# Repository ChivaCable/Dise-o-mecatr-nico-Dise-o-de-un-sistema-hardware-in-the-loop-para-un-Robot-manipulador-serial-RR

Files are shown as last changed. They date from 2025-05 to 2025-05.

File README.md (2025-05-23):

# Sistema-hardware-in-the-loop-para-un-Robot-manipulador-serial-RR

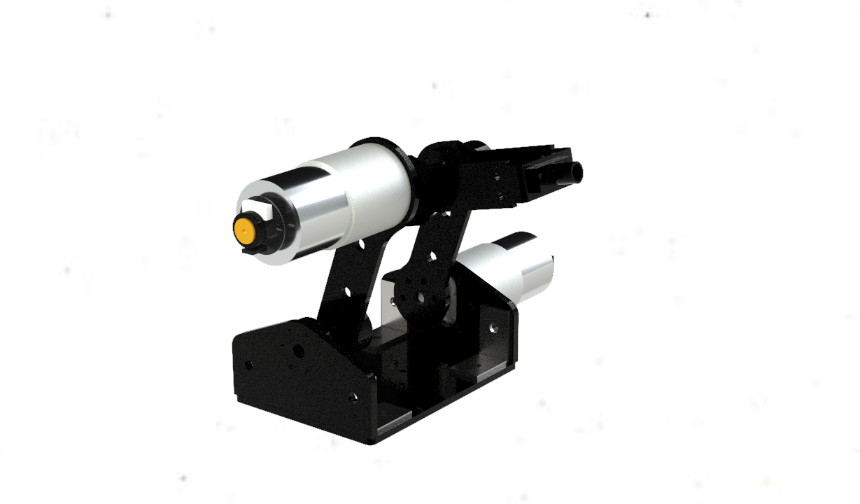
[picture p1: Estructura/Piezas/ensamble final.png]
Image_Alt


# Gz y Rviz

https://github.com/user-attachments/assets/f8c596f3-bc3e-4921-8bc3-12ca6fd54891

# Espacio de trabajo

En este espacio de trabajo usamos ROS 2 y es una estructura de carpetas donde se organizan y construyen los paquetes del sistema robótico. Para trabajar en el espacio de trabajo se debe seguir estos pasos.

# Construir el espacio de trabajo

```bash
cd ros-ws  
colcon build
```

# Configurar el espacio de trabajo
Es necesario cargar ROS2 al sistema y cargar el espacio de trabajo personalizado cada que se realicen cambios.

```bash
source install/setup.bash
source /opt/ros/jazzy/setup.bash
```
# Ejecutar lanzador
El lanzador es el codigo que permite iniciar los multiples nodos que tiene el robot y las configuraciones del mismo de manera simultanea, de manera que con solo un comando se ejecuta el sistema.

```bash
ros2 launch my_robot_planar gazebo_launch.py
```
# Topicos
Gracias a los tópicos en ROS 2, podemos enviar comandos para mover el robot de forma sencilla y eficiente. Esto permite que diferentes nodos se comuniquen y coordinen sus acciones en tiempo real.

# Publicar topicos
En una nueva terminal carga ROS 2 del sistema.
```bash
source /opt/ros/jazzy/setup.bash
```
Lo siguiente es publicar los topicos en la terminal.

Topicos de Gz (usa radianes para mover joint1 y joint2).
```bash
ros2 topic pub /topic_1 std_msgs/msg/Float64 "{data: 1.5}" --once
ros2 topic pub /topic_2 std_msgs/msg/Float64 "{data: 1.5}" --once
```
Topicos del Arduino (usa coordenadas).
```bash
ros2 topic pub /position_command geometry_msgs/msg/Point "{x: -7.97, y: 8.29, z: 0.0}" -1
```
# PCB
Es la base sobre la que se montan y conectan los componentes electrónicos del sistema.

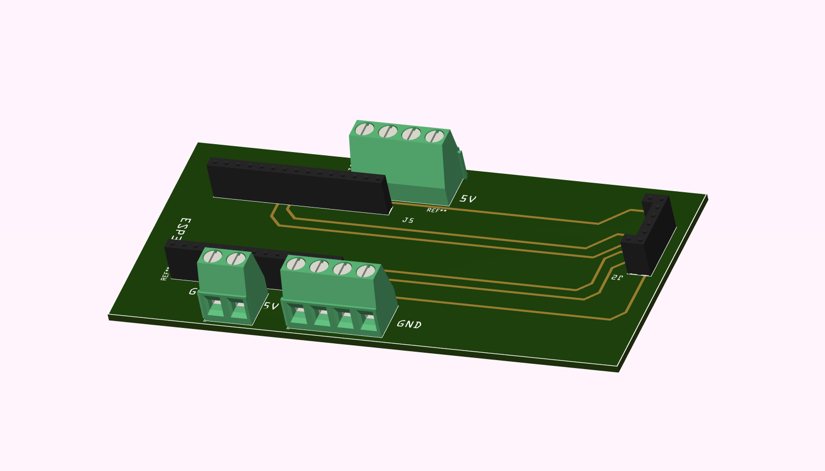
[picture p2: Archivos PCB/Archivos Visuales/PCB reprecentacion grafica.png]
PCB Representación gráfica


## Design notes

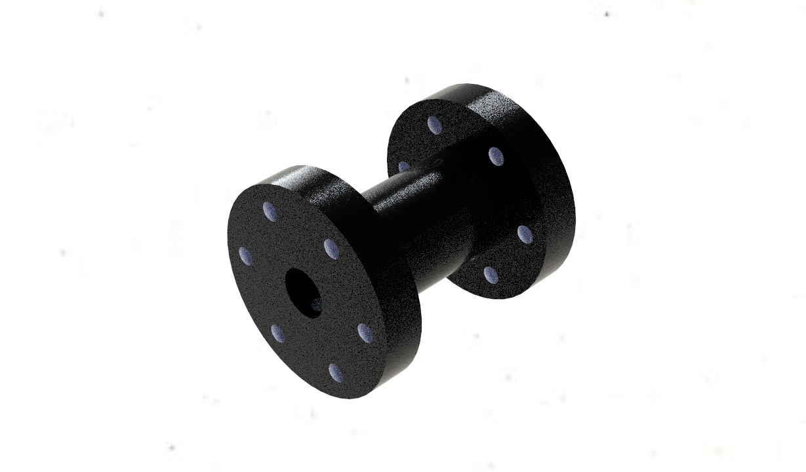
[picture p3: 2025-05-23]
Estructura/Piezas/p3dm double couple_Beauty.jpg

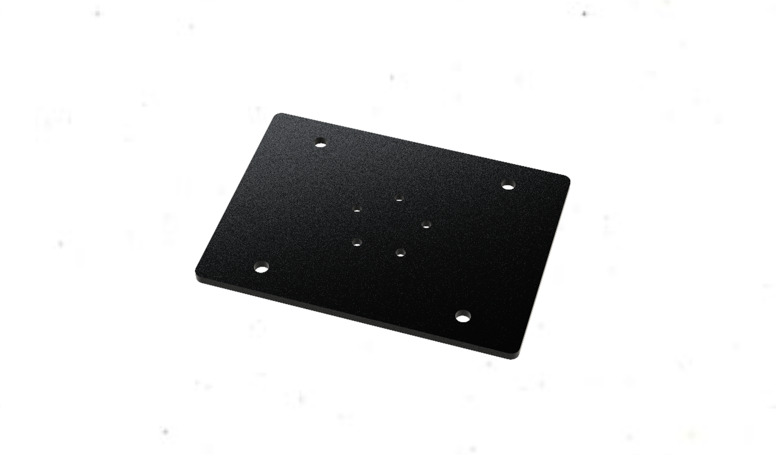
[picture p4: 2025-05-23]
Estructura/Piezas/base.png

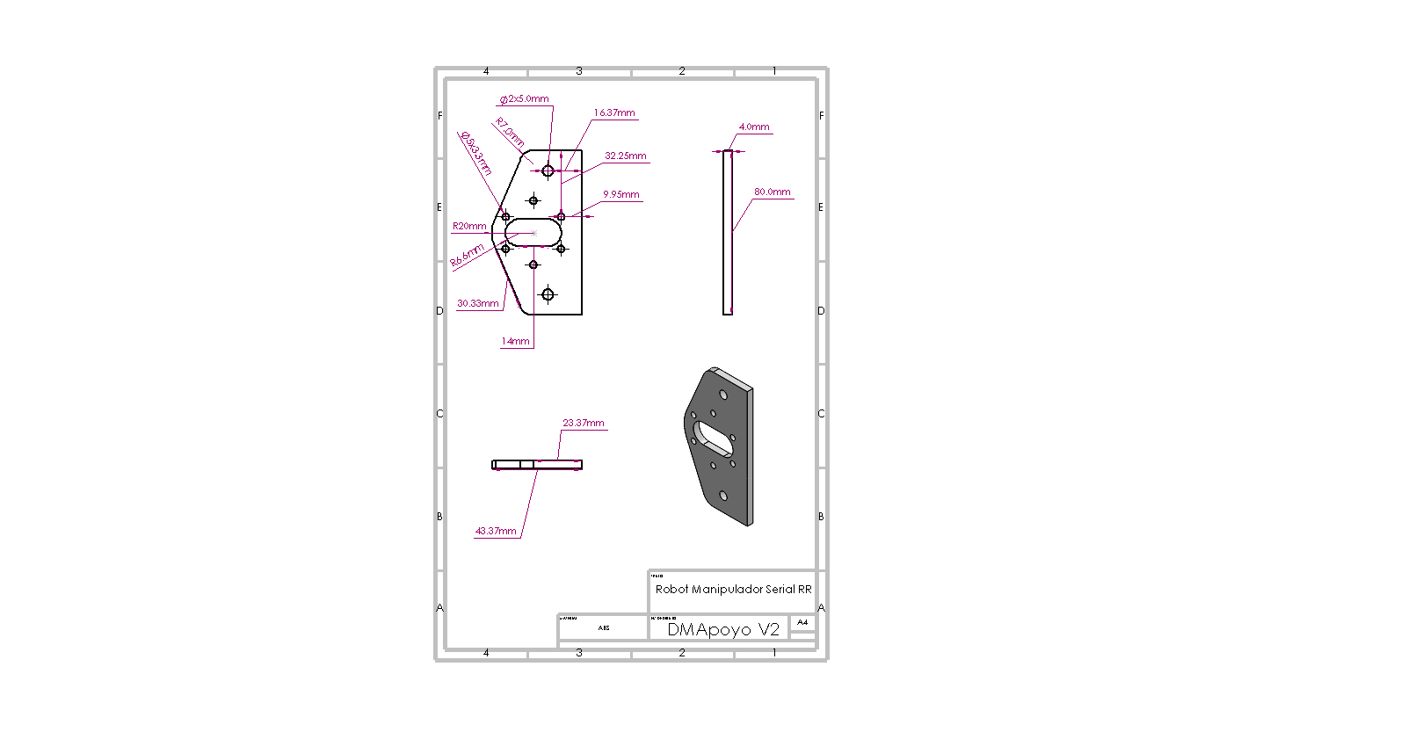
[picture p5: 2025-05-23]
Estructura/Planos/DMApoyo V2.PNG

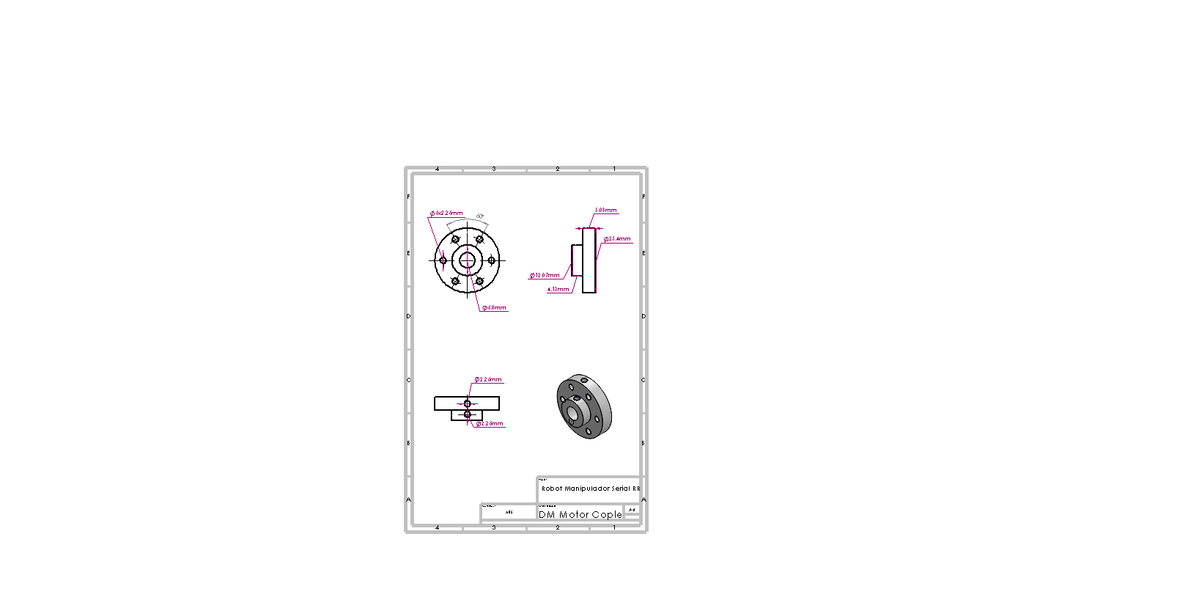
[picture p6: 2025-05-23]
Estructura/Planos/DMMotorCople.PNG

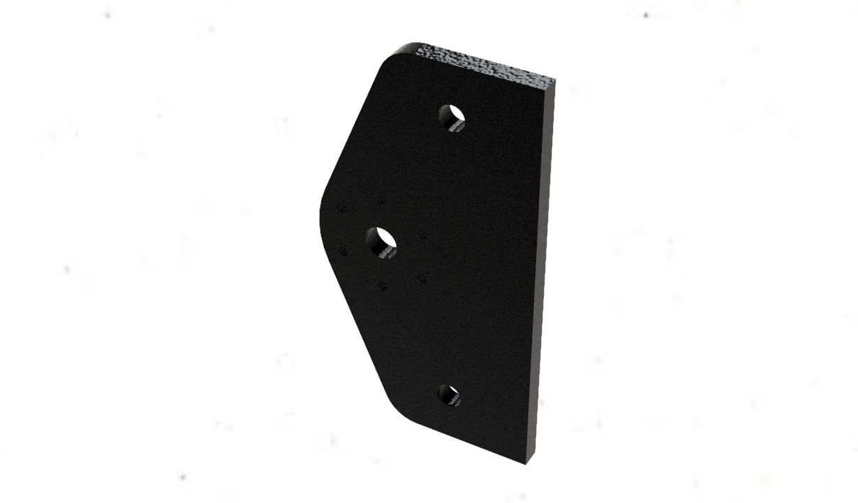
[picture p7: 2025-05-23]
Estructura/Piezas/apoyo1.png

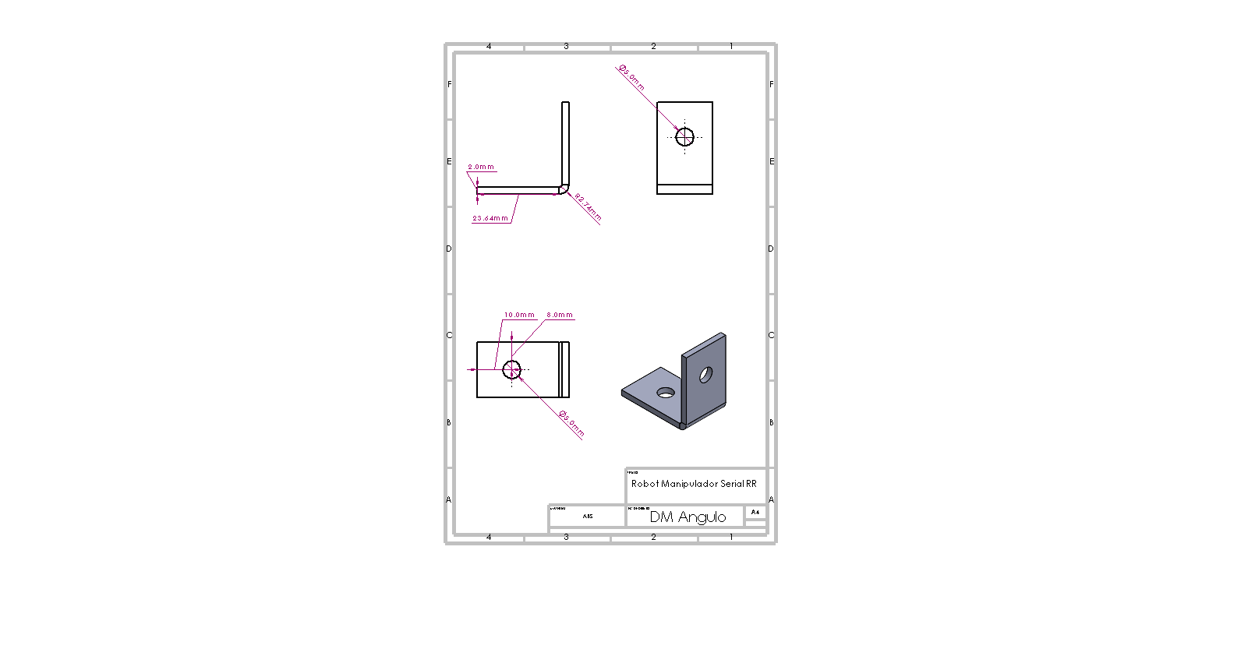
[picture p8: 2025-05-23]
Estructura/Planos/DMAngulo.PNG

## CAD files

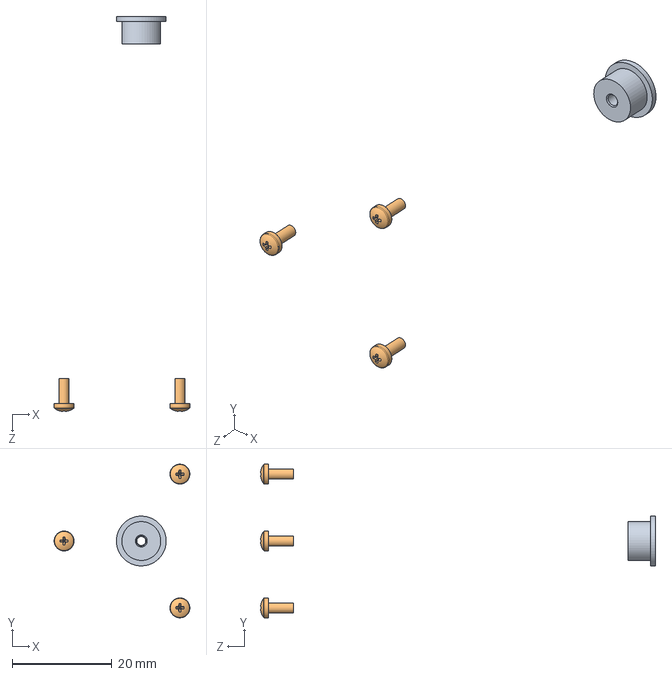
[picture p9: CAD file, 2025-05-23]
Estructura/SolidWorks/DM37D Motor.SLDASM
27.2 x 30.8 x 79.3 mm
DMEncoder Spindle
pan cross head_am x 3

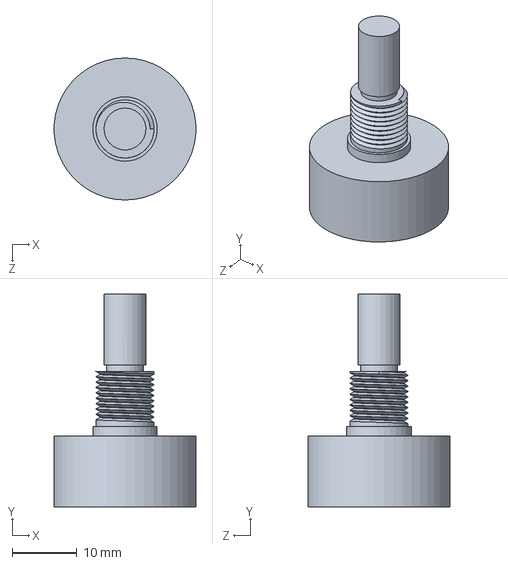
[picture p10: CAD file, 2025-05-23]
Estructura/SolidWorks/Parte 2/dsas.SLDPRT
21.9 x 33.0 x 22.0 mm

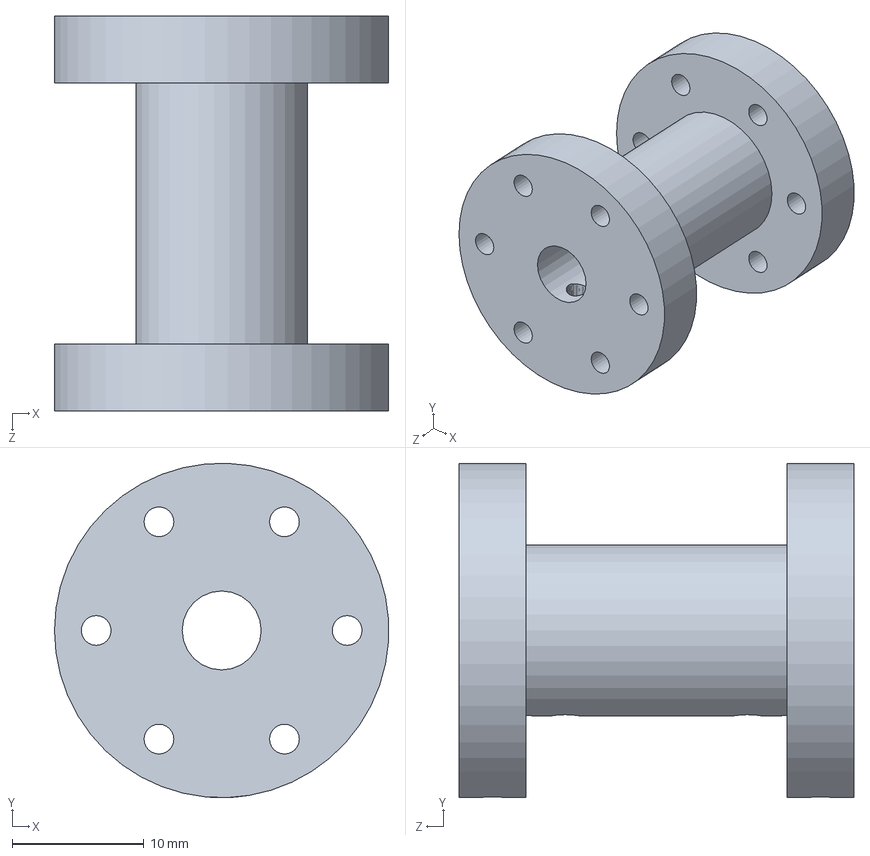
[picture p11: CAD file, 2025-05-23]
Estructura/SolidWorks/Parte3/p3DMDouble Cople.SLDPRT
25.4 x 25.4 x 30.0 mm

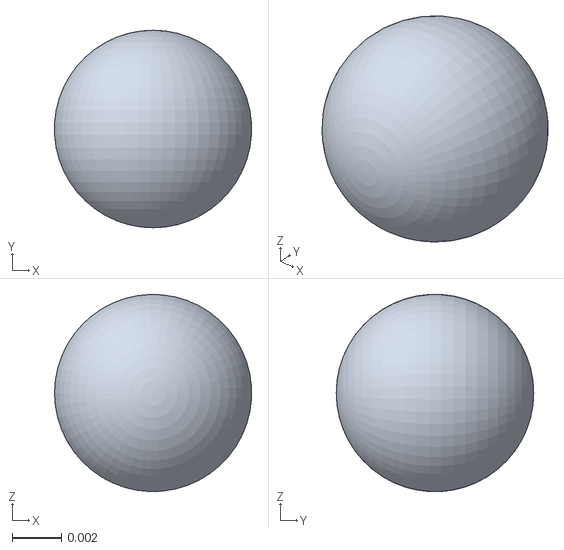
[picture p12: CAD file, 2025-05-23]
my_robot_planar/meshes/End_effctor_Link.STL
0.00798 x 0.008 x 0.00798

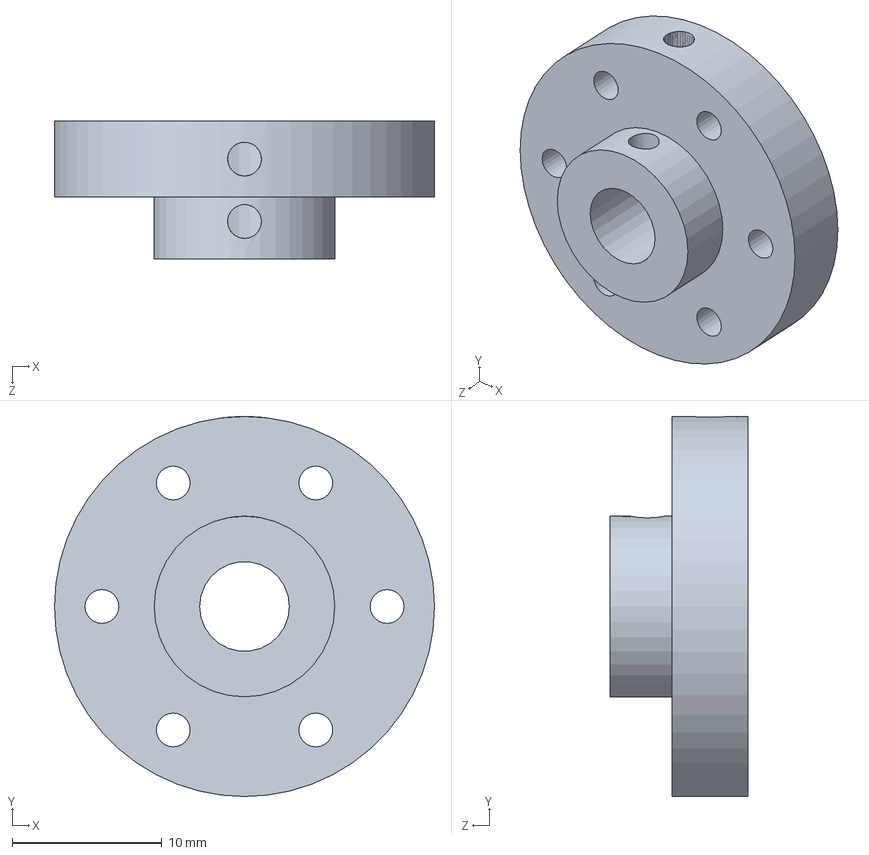
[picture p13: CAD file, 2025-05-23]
Estructura/SolidWorks/Parte3/p3DMMotor Cople.SLDPRT
25.4 x 25.4 x 9.21 mm

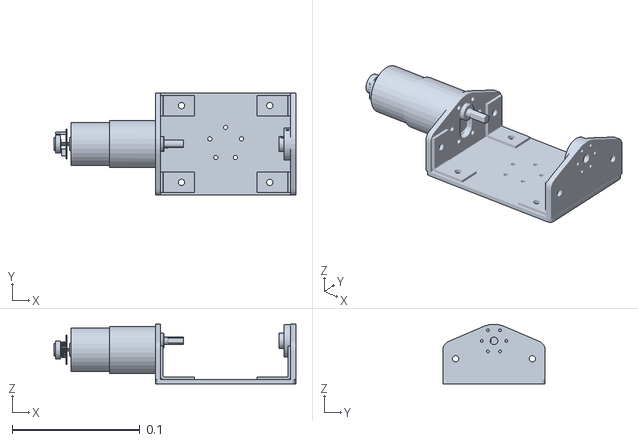
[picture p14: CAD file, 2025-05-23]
my_robot_planar/meshes/base_link.STL
0.189 x 0.08 x 0.0465

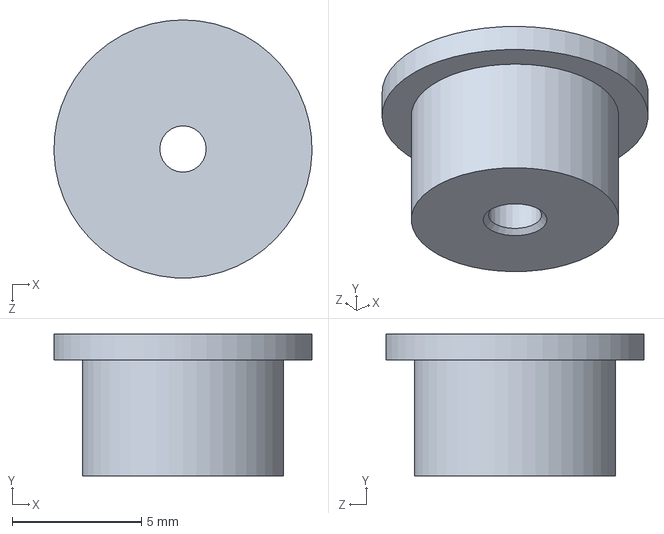
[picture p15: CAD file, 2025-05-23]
Estructura/SolidWorks/DMEncoder Spindle.SLDPRT
10.00 x 5.50 x 10.0 mm

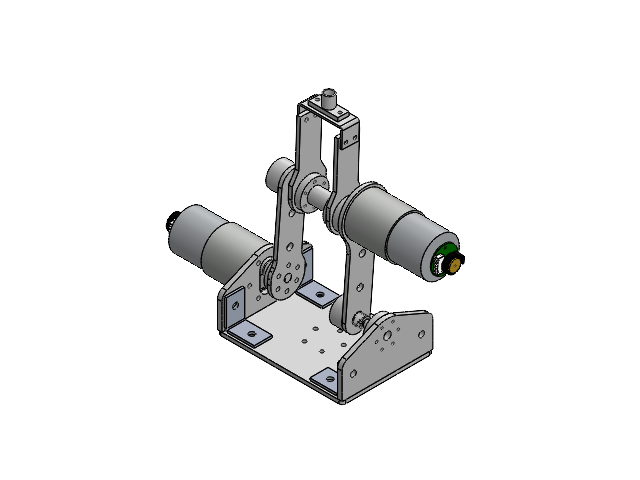
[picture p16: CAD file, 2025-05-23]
Estructura/SolidWorks/Ensamblaje_Final.SLDASM
Partegod1
pieza2
parte3

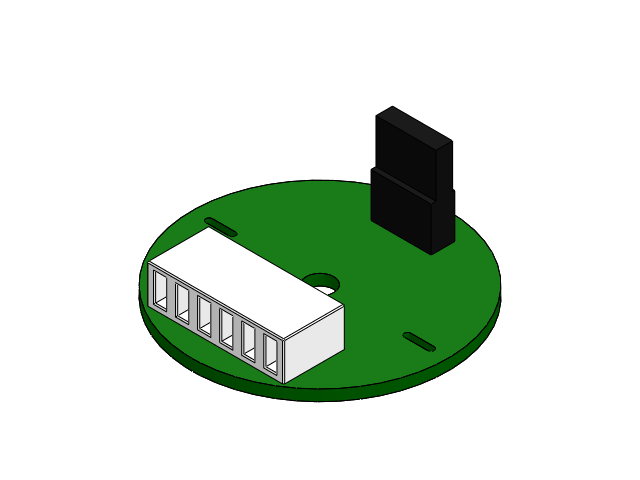
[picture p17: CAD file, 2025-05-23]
Estructura/SolidWorks/Parte 2/DMEncoder PCB Assy.SLDASM
DMEncoder PCB
DMEncoder Terminal
DMEncoder Hall Effect Sensor

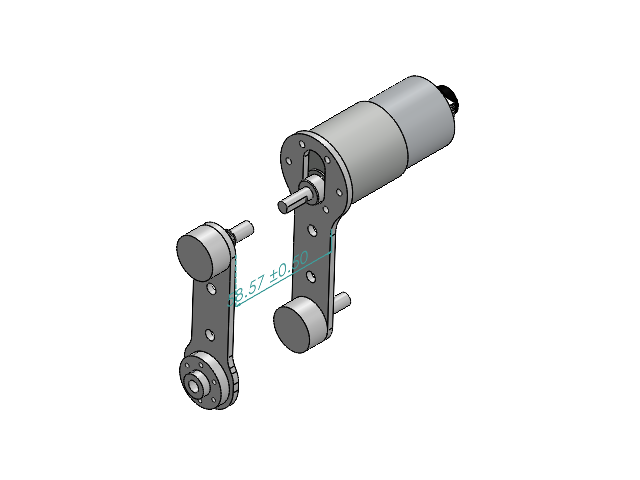
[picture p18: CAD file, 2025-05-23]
Estructura/SolidWorks/Parte 2/Ensamblaje5.SLDASM
DM37D Body
DMMotorshaft
DMEncoder Magnet
DMEncoder Spindle
DMEncoder PCB
DMEncoder Terminal
DMEncoder Hall Effect Sensor
pan cross head_am x 3
DMGear Shaft
DMApoyo Motor1.1
DMBone 2
DMMotor Cople
DMpot
dsas

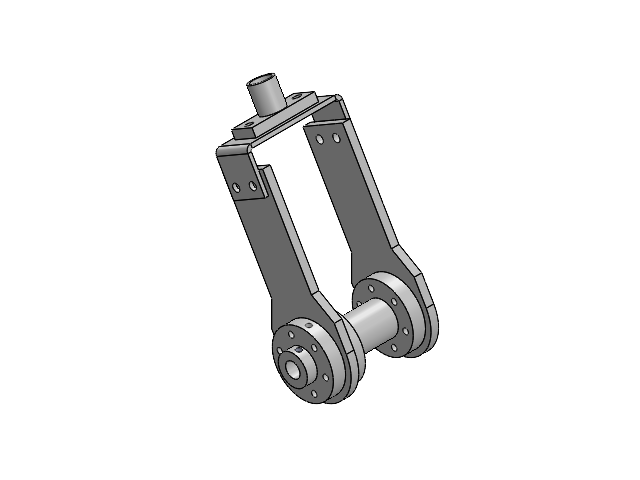
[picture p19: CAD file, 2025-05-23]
Estructura/SolidWorks/Parte3/Ensamblaje3.SLDASM
p3DMDouble Cople
p3DMLamina Gripper
p3DMMotor Cople
p3DMPieza2 x 2
p3End Effector

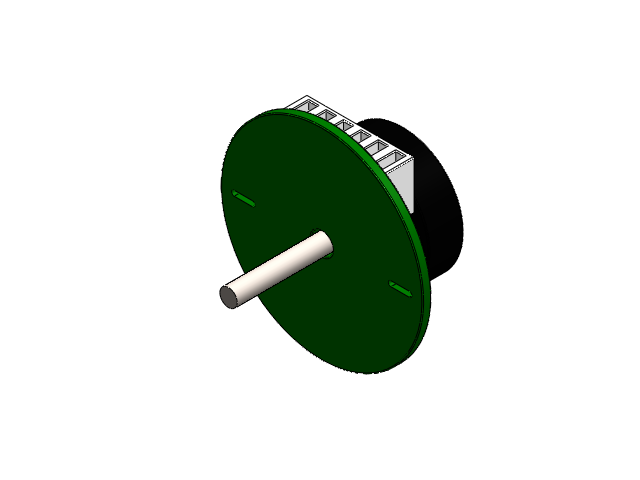
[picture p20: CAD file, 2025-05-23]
Estructura/SolidWorks/Parte 2/DMEncoder.SLDASM
DMMotorshaft
DMEncoder Magnet
DMEncoder Spindle
DMEncoder PCB
DMEncoder Terminal
DMEncoder Hall Effect Sensor

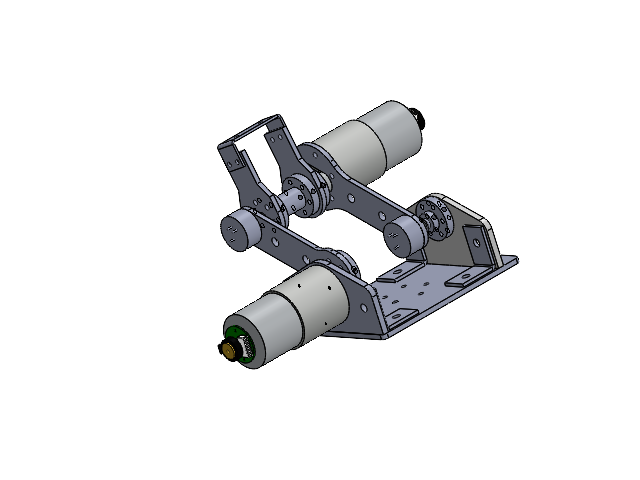
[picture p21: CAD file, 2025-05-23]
Estructura/SolidWorks/Ensamble1.SLDASM
DM37D Body x 2
DMMotorshaft x 2
DMEncoder Magnet x 2
DMEncoder Spindle x 2
DMEncoder PCB x 2
DMEncoder Terminal x 2
DMEncoder Hall Effect Sensor x 2
pan cross head_am x 6
DMGear Shaft x 2
DMMotor Cople x 3
DMPieza2 x 2
DMDouble Cople
DMLamina Gripper
DMpot x 2
DMBone 2
DMApoyo Motor
DMApoyo V2
DMApoyo V2.1
DMAngulo x 4
DMArm Base

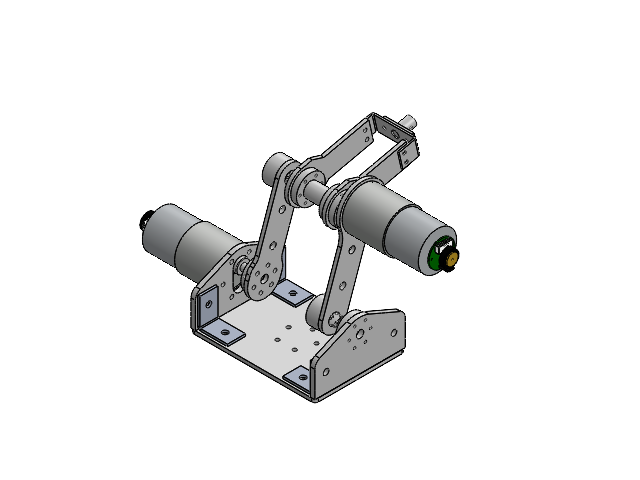
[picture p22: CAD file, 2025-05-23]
Estructura/SolidWorks/Ensamblaje Estructura.SLDASM
DM37D Body x 2
DMMotorshaft x 2
DMEncoder Magnet x 2
DMEncoder Spindle x 2
DMEncoder PCB x 2
DMEncoder Terminal x 2
DMEncoder Hall Effect Sensor x 2
pan cross head_am x 6
DMGear Shaft x 2
DMAngulo x 4
DMApoyo V2
DMApoyo V2.1
DMArm Base
DMBone 2
DMDouble Cople
DMLamina Gripper
DMMotor Cople x 3
DMPieza2 x 2
DMpot x 2
End Effector
DMApoyo Motor1.1

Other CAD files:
Estructura/SolidWorks/DMEncoder.SLDASM
Estructura/SolidWorks/Parte 2/DM37D Motor.SLDASM
Estructura/SolidWorks/Ensamblaje1.1.SLDASM
Estructura/SolidWorks/Apoyo Motor.SLDPRT
Estructura/SolidWorks/DM37D Body.SLDPRT
Estructura/SolidWorks/DMAngulo.SLDPRT
Estructura/SolidWorks/DMApoyo Motor1.1.SLDPRT
Estructura/SolidWorks/DMApoyo V2.1.SLDPRT
Estructura/SolidWorks/DMApoyo V2.SLDPRT
Estructura/SolidWorks/DMArm Base.SLDPRT
Estructura/SolidWorks/DMBone 2.SLDPRT
Estructura/SolidWorks/DMDouble Cople.SLDPRT
Estructura/SolidWorks/DMEncoder Hall Effect Sensor.SLDPRT
Estructura/SolidWorks/DMEncoder Magnet.SLDPRT
Estructura/SolidWorks/DMEncoder PCB.SLDPRT
Estructura/SolidWorks/DMEncoder Terminal.SLDPRT
Estructura/SolidWorks/DMGear Shaft.SLDPRT
Estructura/SolidWorks/DMLamina Gripper.SLDPRT
Estructura/SolidWorks/DMMotor Cople.SLDPRT
Estructura/SolidWorks/DMMotorshaft.SLDPRT
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

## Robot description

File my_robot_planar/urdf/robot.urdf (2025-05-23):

<robot name="my_robot">
  <link name="base_link">
    <inertial>
      <origin xyz="-0.045568 -6.0363e-06 0.016416" rpy="0 0 0"/>
      <mass value="0.12503"/>
      <inertia ixx="3.9011e-05" ixy="-4.4034e-10" ixz="-9.4868e-09" iyy="5.9546e-05" iyz="1.2812e-09" izz="8.1796e-05"/>
    </inertial>
    <visual name="base_link_visual">
      <origin xyz="0 0 0" rpy="0 0 0"/>
      <geometry>
        <mesh filename="package://my_robot_planar/meshes/base_link.STL" scale="1 1 1"/>
      </geometry>
      <material name="gray_blue">
        <color rgba="0.79216 0.81961 0.93333 1"/>
      </material>
    </visual>
    <collision name="base_link_collision">
      <origin xyz="0 0 0" rpy="0 0 0"/>
      <geometry>
        <mesh filename="package://my_robot_planar/meshes/base_link.STL" scale="1 1 1"/>
      </geometry>
    </collision>
  </link>

  <joint name="joint1" type="revolute">
    <origin xyz="-0.043204 -0.00013674 0.030451" rpy="-1.5708 -1.5271 1.5708"/>
    <parent link="base_link"/>
    <child link="Motor1_Link"/>
    <axis xyz="0 0 1"/>
    <limit lower="-3.1416" upper="3.1416" effort="100" velocity="100"/>
    <dynamics damping="0.1" friction="0.1"/>
  </joint>

  <link name="Motor1_Link">
    <inertial>
      <origin xyz="0.002191 0.064828 -0.085027" rpy="0 0 0"/>
      <mass value="0.094024"/>
      <inertia ixx="3.9845e-05" ixy="-3.4856e-07" ixz="6.7838e-10" iyy="2.9913e-05" iyz="9.5762e-09" izz="2.2849e-05"/>
    </inertial>
    <visual name="Motor1_Link_visual">
      <origin xyz="0 0 0" rpy="0 0 0"/>
      <geometry>
        <mesh filename="package://my_robot_planar/meshes/Motor1_Link.STL" scale="1 1 1"/>
      </geometry>
      <material name="gray_blue">
        <color rgba="0.79216 0.81961 0.93333 1"/>
      </material>
    </visual>
    <collision name="Motor1_Link_collision">
      <origin xyz="0 0 0" rpy="0 0 0"/>
      <geometry>
        <mesh filename="package://my_robot_planar/meshes/Motor1_Link.STL" scale="1 1 1"/>
      </geometry>
    </collision>
  </link>

  <joint name="joint2" type="revolute">
    <origin xyz="0.0024029 0.070153 -0.047398" rpy="0 0 -0.55803"/>
    <parent link="Motor1_Link"/>
    <child link="Motor2_Link"/>
    <axis xyz="0 0 1"/>
    <limit lower="-3.1416" upper="3.1416" effort="100" velocity="100"/>
    <dynamics damping="0.1" friction="0.1"/>
  </joint>

  <link name="Motor2_Link">
    <inertial>
      <origin xyz="-0.0095616 0.016516 0.0024794" rpy="0 0 0"/>
      <mass value="0.022468"/>
      <inertia ixx="5.2162e-06" ixy="1.6765e-06" ixz="6.8852e-15" iyy="3.2892e-06" iyz="1.1051e-11" izz="5.5835e-06"/>
    </inertial>
    <visual name="Motor2_Link_visual">
      <origin xyz="0 0 0" rpy="0 0 0"/>
      <geometry>
        <mesh filename="package://my_robot_planar/meshes/Motor2_Link.STL" scale="1 1 1"/>
      </geometry>
      <material name="gray_blue">
        <color rgba="0.79216 0.81961 0.93333 1"/>
      </material>
    </visual>
    <collision name="Motor2_Link_collision">
      <origin xyz="0 0 0" rpy="0 0 0"/>
      <geometry>
        <mesh filename="package://my_robot_planar/meshes/Motor2_Link.STL" scale="1 1 1"/>
      </geometry>
    </collision>
  </link>

  <joint name="joint_End" type="fixed">
    <origin xyz="-0.041151 0.071211 0" rpy="1.651 0.11053 -1.8717"/>
    <parent link="Motor2_Link"/>
    <child link="End_effctor_Link"/>
  </joint>

  <link name="End_effctor_Link">
    <inertial>
      <origin xyz="0 0 0" rpy="0 0 0"/>
      <mass value="0.00026808"/>
      <inertia ixx="1.7157e-09" ixy="0" ixz="0" iyy="1.7157e-09" iyz="0" izz="1.7157e-09"/>
    </inertial>
    <visual name="End_effctor_Link_visual">
      <origin xyz="0 0 0" rpy="0 0 0"/>
      <geometry>
        <mesh filename="package://my_robot_planar/meshes/End_effctor_Link.STL" scale="1 1 1"/>
      </geometry>
      <material name="gray_blue">
        <color rgba="0.79216 0.81961 0.93333 1"/>
      </material>
    </visual>
    <collision name="End_effctor_Link_collision">
      <origin xyz="0 0 0" rpy="0 0 0"/>
      <geometry>
        <mesh filename="package://my_robot_planar/meshes/End_effctor_Link.STL" scale="1 1 1"/>
      </geometry>
    </collision>
  </link>
</robot>

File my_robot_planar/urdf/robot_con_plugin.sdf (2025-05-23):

<sdf version='1.11'>
  <model name='my_robot'>
    <link name='base_link'>
      <inertial>
        <pose>-0.045567999999999997 -6.0363000000000001e-06 0.016416 0 0 0</pose>
        <mass>0.12503</mass>
        <inertia>
          <ixx>3.9011000000000003e-05</ixx>
          <ixy>-4.4034e-10</ixy>
          <ixz>-9.4868e-09</ixz>
          <iyy>5.9546000000000002e-05</iyy>
          <iyz>1.2812000000000001e-09</iyz>
          <izz>8.1796000000000001e-05</izz>
        </inertia>
      </inertial>
      <collision name='base_link_collision'>
        <pose>0 0 0 0 0 0</pose>
        <geometry>
          <mesh>
            <scale>1 1 1</scale>
            <uri>file:///home/chiva/ros2_ws/src/my_robot_planar/meshes/base_link.STL</uri>
          </mesh>
        </geometry>
      </collision>
      <visual name='base_link_visual'>
        <pose>0 0 0 0 0 0</pose>
        <geometry>
          <mesh>
            <scale>1 1 1</scale>
            <uri>file:///home/chiva/ros2_ws/src/my_robot_planar/meshes/base_link.STL</uri>
          </mesh>
        </geometry>
        <material>
          <diffuse>0.990199983 1 1 1</diffuse>
          <ambient>0.990199983 1 1 1</ambient>
        </material>
      </visual>
    </link>
    <joint name='joint1' type='revolute'>
      <pose relative_to='base_link'>-0.043203999999999999 -0.00013674 0.030450999999999999 -1.5708000000000004 -1.5271000000000059 1.5708000000000002</pose>
      <parent>base_link</parent>
      <child>Motor1_Link</child>
      <axis>
        <xyz>0 0 1</xyz>
        <limit>
          <effort>100</effort>
          <velocity>100</velocity>
          <lower>-inf</lower>
          <upper>inf</upper>
        </limit>
        <dynamics>
          <damping>0.10000000000000001</damping>
          <friction>0.10000000000000001</friction>
          <spring_reference>0</spring_reference>
          <spring_stiffness>0</spring_stiffness>
        </dynamics>
      </axis>
    </joint>
    <link name='Motor1_Link'>
      <pose relative_to='joint1'>0 0 0 0 0 0</pose>
      <inertial>
        <pose>0.0021909999999999998 0.064827999999999997 -0.085027000000000005 0 0 0</pose>
        <mass>0.094023999999999996</mass>
        <inertia>
          <ixx>3.9845000000000002e-05</ixx>
          <ixy>-3.4855999999999999e-07</ixy>
          <ixz>6.7837999999999999e-10</ixz>
          <iyy>2.9913e-05</iyy>
          <iyz>9.5762000000000001e-09</iyz>
          <izz>2.2849000000000001e-05</izz>
        </inertia>
      </inertial>
      <collision name='Motor1_Link_collision'>
        <pose>0 0 0 0 0 0</pose>
        <geometry>
          <mesh>
            <scale>1 1 1</scale>
            <uri>file:///home/chiva/ros2_ws/src/my_robot_planar/meshes/Motor1_Link.STL</uri>
          </mesh>
        </geometry>
      </collision>
      <visual name='Motor1_Link_visual'>
        <pose>0 0 0 0 0 0</pose>
        <geometry>
          <mesh>
            <scale>1 1 1</scale>
            <uri>file:///home/chiva/ros2_ws/src/my_robot_planar/meshes/Motor1_Link.STL</uri>
          </mesh>
        </geometry>
        <material>
          <diffuse>0.990199983 1 1 1</diffuse>
          <ambient>0.990199983 1 1 1</ambient>
        </material>
      </visual>
    </link>
    <joint name='joint2' type='revolute'>
      <pose relative_to='Motor1_Link'>0.0024028999999999999 0.070152999999999993 -0.047398000000000003 0 0 -0.55803000000000003</pose>
      <parent>Motor1_Link</parent>
      <child>Motor2_Link</child>
      <axis>
        <xyz>0 0 1</xyz>
        <limit>
          <effort>100</effort>
          <velocity>100</velocity>
          <lower>-inf</lower>
          <upper>inf</upper>
        </limit>
        <dynamics>
          <damping>0.10000000000000001</damping>
          <friction>0.10000000000000001</friction>
          <spring_reference>0</spring_reference>
          <spring_stiffness>0</spring_stiffness>
        </dynamics>
      </axis>
    </joint>
    <link name='Motor2_Link'>
      <pose relative_to='joint2'>0 0 0 0 0 0</pose>
      <inertial>
        <pose>-0.0099340690602777604 0.017160906052406569 0.0024501655166589849 0 0 0</pose>
        <mass>0.022736079999999999</mass>
        <inertia>
          <ixx>6.012061101716937e-06</ixx>
          <ixy>2.134222482919513e-06</ixy>
          <ixz>-2.0749186352767712e-08</ixz>
          <iyy>3.556904423631972e-06</iyy>
          <iyz>3.5936935130456297e-08</iyz>
          <izz>6.6420926853136944e-06</izz>
        </inertia>
      </inertial>
      <collision name='Motor2_Link_collision'>
        <pose>0 0 0 0 0 0</pose>
        <geometry>
          <mesh>
            <scale>1 1 1</scale>
            <uri>file:///home/chiva/ros2_ws/src/my_robot_planar/meshes/Motor2_Link.STL</uri>
          </mesh>
        </geometry>
      </collision>
      <collision name='Motor2_Link_fixed_joint_lump__End_effctor_Link_collision_1'>
        <pose>-0.041151 0.071210999999999997 0 1.651 0.11053000000000004 -1.8716999999999999</pose>
        <geometry>
          <mesh>
            <scale>1 1 1</scale>
            <uri>file:///home/chiva/ros2_ws/src/my_robot_planar/meshes/End_effctor_Link.STL</uri>
          </mesh>
        </geometry>
      </collision>
      <visual name='Motor2_Link_visual'>
        <pose>0 0 0 0 0 0</pose>
        <geometry>
          <mesh>
            <scale>1 1 1</scale>
            <uri>file:///home/chiva/ros2_ws/src/my_robot_planar/meshes/Motor2_Link.STL</uri>
          </mesh>
        </geometry>
        <material>
          <diffuse>0.990199983 1 1 1</diffuse>
          <ambient>0.990199983 1 1 1</ambient>
        </material>
      </visual>
      <visual name='Motor2_Link_fixed_joint_lump__End_effctor_Link_visual_1'>
        <pose>-0.041151 0.071210999999999997 0 1.651 0.11053000000000004 -1.8716999999999999</pose>
        <geometry>
          <mesh>
            <scale>1 1 1</scale>
            <uri>file:///home/chiva/ros2_ws/src/my_robot_planar/meshes/End_effctor_Link.STL</uri>
          </mesh>
        </geometry>
        <material>
          <diffuse>0.990199983 1 1 1</diffuse>
          <ambient>0.990199983 1 1 1</ambient>
        </material>
      </visual>
    </link>
    <frame name='joint_End' attached_to='Motor2_Link'>
      <pose>-0.041151 0.071210999999999997 0 1.651 0.11053000000000021 -1.8716999999999999</pose>
    </frame>
    <frame name='End_effctor_Link' attached_to='joint_End'>
      <pose>0 0 0 0 0 0</pose>
    </frame>

    <joint name="fixed_to_ground" type="fixed">
      <parent>world</parent>
      <child>base_link</child>
    </joint>


    <plugin filename="gz-sim-joint-position-controller-system" name="gz::sim::systems::JointPositionController">
      <joint_name>joint1</joint_name>
      <topic>/topic_1</topic>  
      <p_gain>1.5</p_gain>
      <i_gain>0.1</i_gain>
      <d_gain>0.001</d_gain>
      <i_max>1</i_max>
      <i_min>-1</i_min>
      <cmd_max>1000</cmd_max>
      <cmd_min>-1000</cmd_min>
    </plugin>

    <plugin filename="gz-sim-joint-position-controller-system" name="gz::sim::systems::JointPositionController">
      <joint_name>joint2</joint_name>
      <topic>/topic_2</topic>
      <p_gain>1.4</p_gain>
      <i_gain>0.1</i_gain>
      <d_gain>0.1</d_gain>
      <i_max>1</i_max>
      <i_min>-1</i_min>
      <cmd_max>1000</cmd_max>
      <cmd_min>-1000</cmd_min>
    </plugin>

    
    <plugin filename="gz-sim-joint-state-publisher-system" name="gz::sim::systems::JointStatePublisher">
        <topic>/joint_states</topic>
        <joint_name>joint1</joint_name>
        <joint_name>joint2</joint_name>
    </plugin>
  </model>
</sdf>

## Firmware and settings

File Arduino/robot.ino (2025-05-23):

#include <Arduino.h>
#include <micro_ros_arduino.h>
#include <rcl/rcl.h>
#include <rclc/rclc.h>
#include <rclc/executor.h>
#include <std_msgs/msg/int16.h>
#include <geometry_msgs/msg/point.h>

const int M1_PWM_PIN = 25;
const int M1_IN1_PIN = 27;
const int M1_IN2_PIN = 26;
const int M1_ENC_A_PIN = 34;
const int M1_ENC_B_PIN = 35;

const int M2_PWM_PIN = 23;
const int M2_IN1_PIN = 22;
const int M2_IN2_PIN = 21;
const int M2_ENC_A_PIN = 19;
const int M2_ENC_B_PIN = 18;

const float PULSOS_POR_VUELTA = 618.2;
const float PULSOS_POR_GRADO = PULSOS_POR_VUELTA / 360.0;
const unsigned long TIMEOUT_MS = 3000;
const int ANGULO_MAXIMO = 120;
const int VELOCIDAD_Q1 = 600;

float Kp_q2 = 1.0, Ki_q2 = 0.01, Kd_q2 = 2.5;
const int PWM_MAX = 255;

const float a1 = 1.32;
const float a2 = 6.97;
const float a3 = 7.97;

volatile int encoder1_count = 0;
volatile int encoder2_count = 0;

rcl_node_t node;
rcl_publisher_t joint_state_publisher;
rcl_subscription_t q1_subscriber;
rcl_subscription_t q2_subscriber;
rcl_subscription_t pos_subscriber;

geometry_msgs__msg__Point joint_state_msg;
std_msgs__msg__Int16 q1_msg;
std_msgs__msg__Int16 q2_msg;
geometry_msgs__msg__Point pos_msg;

rclc_executor_t executor;
rcl_allocator_t allocator;
rclc_support_t support;

float q1_actual = 0;
float q2_actual = 0;

void IRAM_ATTR encoder1ISR() {
  encoder1_count += digitalRead(M1_ENC_B_PIN) ? 1 : -1;
}

void IRAM_ATTR encoder2ISR() {
  encoder2_count += digitalRead(M2_ENC_B_PIN) ? 1 : -1;
}

void set_motor(int pwm_pin, int in1_pin, int in2_pin, int direction, int speed) {
  speed = constrain(speed, 0, PWM_MAX);
  analogWrite(pwm_pin, speed);
  digitalWrite(in1_pin, direction > 0 ? HIGH : LOW);
  digitalWrite(in2_pin, direction > 0 ? LOW : HIGH);
}

void stop_motor(int pwm_pin, int in1_pin, int in2_pin) {
  analogWrite(pwm_pin, 0);
  digitalWrite(in1_pin, LOW);
  digitalWrite(in2_pin, LOW);
}

int get_encoder1() { return encoder1_count; }
int get_encoder2() { return encoder2_count; }

void mover_motor_a_angulo_relativo(int pwm_pin, int in1_pin, int in2_pin, int (*encoder_getter)(),
                                  float angulo_actual, int angulo_objetivo, int velocidad, float &nueva_posicion) {
  float delta_angulo = angulo_objetivo - angulo_actual;
  int pulsos_objetivo = abs(delta_angulo) * PULSOS_POR_GRADO;
  int direccion = (delta_angulo > 0) ? 1 : -1;

  set_motor(pwm_pin, in1_pin, in2_pin, direccion, velocidad);

  int inicio = encoder_getter();
  unsigned long t_inicio = millis();
  while (true) {
    int recorrido = abs(encoder_getter() - inicio);
    if (recorrido >= pulsos_objetivo) break;
    if (millis() - t_inicio > TIMEOUT_MS) break;
    delay(10);
  }

  stop_motor(pwm_pin, in1_pin, in2_pin);
  nueva_posicion = angulo_objetivo;
}

void mover_motor_PID(int pwm_pin, int in1_pin, int in2_pin, int (*encoder_getter)(),
                     float angulo_actual, int angulo_objetivo, float &nueva_posicion,
                     float Kp, float Ki, float Kd) {

  int objetivo_pulsos = angulo_objetivo * PULSOS_POR_GRADO;
  float error, integral = 0, derivada, prev_error = 0;
  unsigned long t0 = millis();

  while (millis() - t0 < TIMEOUT_MS) {
    int lectura = encoder_getter();
    error = objetivo_pulsos - lectura;
    integral += error;
    derivada = error - prev_error;
    prev_error = error;

    int pwm = Kp * error + Ki * integral + Kd * derivada;
    pwm = constrain(pwm, -PWM_MAX, PWM_MAX);
    int dir = (pwm >= 0) ? 1 : -1;
    set_motor(pwm_pin, in1_pin, in2_pin, dir, abs(pwm));

    if (abs(error) < 2) break;
    delay(10);
  }

  stop_motor(pwm_pin, in1_pin, in2_pin);
  nueva_posicion = angulo_objetivo;
}

bool resolver_cinematica_inversa(float x, float y, float &q1, float &q2) {
  float D = y - a1;
  float cos_q2 = (x * x + D * D - a2 * a2 - a3 * a3) / (2 * a2 * a3);
  if (cos_q2 < -1.0 || cos_q2 > 1.0) return false;
  float sin_q2 = sqrt(1 - cos_q2 * cos_q2);
  q2 = degrees(atan2(sin_q2, cos_q2));
  q1 = degrees(atan2(D, x) - atan2(a3 * sin_q2, a2 + a3 * cos_q2));
  return true;
}

void publish_joint_state() {
  joint_state_msg.x = radians(q1_actual);
  joint_state_msg.y = radians(q2_actual);
  rcl_publish(&joint_state_publisher, &joint_state_msg, NULL);
}

void q1_callback(const void * msgin) {
  const std_msgs__msg__Int16 * msg = (const std_msgs__msg__Int16 *)msgin;
  int ang = msg->data;
  mover_motor_a_angulo_relativo(M1_PWM_PIN, M1_IN1_PIN, M1_IN2_PIN, get_encoder1, 
                               q1_actual, ang, VELOCIDAD_Q1, q1_actual);
  publish_joint_state();
}

void q2_callback(const void * msgin) {
  const std_msgs__msg__Int16 * msg = (const std_msgs__msg__Int16 *)msgin;
  int ang = msg->data;
  mover_motor_PID(M2_PWM_PIN, M2_IN1_PIN, M2_IN2_PIN, get_encoder2,
                 q2_actual, ang, q2_actual, Kp_q2, Ki_q2, Kd_q2);
  publish_joint_state();
}

void pos_callback(const void * msgin) {
  const geometry_msgs__msg__Point * msg = (const geometry_msgs__msg__Point *)msgin;
  float x = msg->x;
  float y = msg->y;
  float q1_calc, q2_calc;

  if (resolver_cinematica_inversa(x, y, q1_calc, q2_calc)) {
    mover_motor_a_angulo_relativo(M1_PWM_PIN, M1_IN1_PIN, M1_IN2_PIN, get_encoder1,
                                q1_actual, (int)q1_calc, VELOCIDAD_Q1, q1_actual);
    mover_motor_PID(M2_PWM_PIN, M2_IN1_PIN, M2_IN2_PIN, get_encoder2,
                   q2_actual, (int)q2_calc, q2_actual, Kp_q2, Ki_q2, Kd_q2);
    publish_joint_state();
  }
}

void setup() {
  pinMode(M1_IN1_PIN, OUTPUT);
  pinMode(M1_IN2_PIN, OUTPUT);
  pinMode(M2_IN1_PIN, OUTPUT);
  pinMode(M2_IN2_PIN, OUTPUT);

  pinMode(M1_ENC_A_PIN, INPUT_PULLUP);
  pinMode(M1_ENC_B_PIN, INPUT_PULLUP);
  pinMode(M2_ENC_A_PIN, INPUT_PULLUP);
  pinMode(M2_ENC_B_PIN, INPUT_PULLUP);

  attachInterrupt(digitalPinToInterrupt(M1_ENC_A_PIN), encoder1ISR, RISING);
  attachInterrupt(digitalPinToInterrupt(M2_ENC_A_PIN), encoder2ISR, RISING);

  set_microros_transports();
  delay(2000);

  allocator = rcl_get_default_allocator();
  rclc_support_init(&support, 0, NULL, &allocator);
  rclc_node_init_default(&node, "brazo_robotico_node", "", &support);

  rclc_publisher_init_default(
    &joint_state_publisher,
    &node,
    ROSIDL_GET_MSG_TYPE_SUPPORT(geometry_msgs, msg, Point),
    "joint_state");

  rclc_subscription_init_default(
    &q1_subscriber,
    &node,
    ROSIDL_GET_MSG_TYPE_SUPPORT(std_msgs, msg, Int16),
    "q1_command");

  rclc_subscription_init_default(
    &q2_subscriber,
    &node,
    ROSIDL_GET_MSG_TYPE_SUPPORT(std_msgs, msg, Int16),
    "q2_command");

  rclc_subscription_init_default(
    &pos_subscriber,
    &node,
    ROSIDL_GET_MSG_TYPE_SUPPORT(geometry_msgs, msg, Point),
    "position_command");

  rclc_executor_init(&executor, &support.context, 3, &allocator);
  rclc_executor_add_subscription(&executor, &q1_subscriber, &q1_msg, &q1_callback, ON_NEW_DATA);
  rclc_executor_add_subscription(&executor, &q2_subscriber, &q2_msg, &q2_callback, ON_NEW_DATA);
  rclc_executor_add_subscription(&executor, &pos_subscriber, &pos_msg, &pos_callback, ON_NEW_DATA);
}

void loop() {
  rclc_executor_spin_some(&executor, RCL_MS_TO_NS(100));
}

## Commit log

2025-05-23 Se agrega el Proyecto
2025-05-23 Se agregan todos los archivos del proyecto
    [End_effctor_Link.STL, Motor1_Link.STL, Motor2_Link.STL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]
2025-05-23 Mis cambios locales antes del pull
    [robot_con_plugin.sdf]
